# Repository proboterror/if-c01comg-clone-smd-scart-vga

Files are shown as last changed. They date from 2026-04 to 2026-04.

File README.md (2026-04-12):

IF-C01COMG Clone board SMD Full size - with SCART and DSUB-15 (VGA 15KHz) inputs.<br>
Separate H/V and combined sync supported for DSUB-15 input.

BNC connectors option removed<br>
RCA audio connectors replaced with 3.5 mm audio jack<br>
Switches changed to ALPS SPUJ190900 / SPUJ193700<br>

Project migrated to KiCad 8.

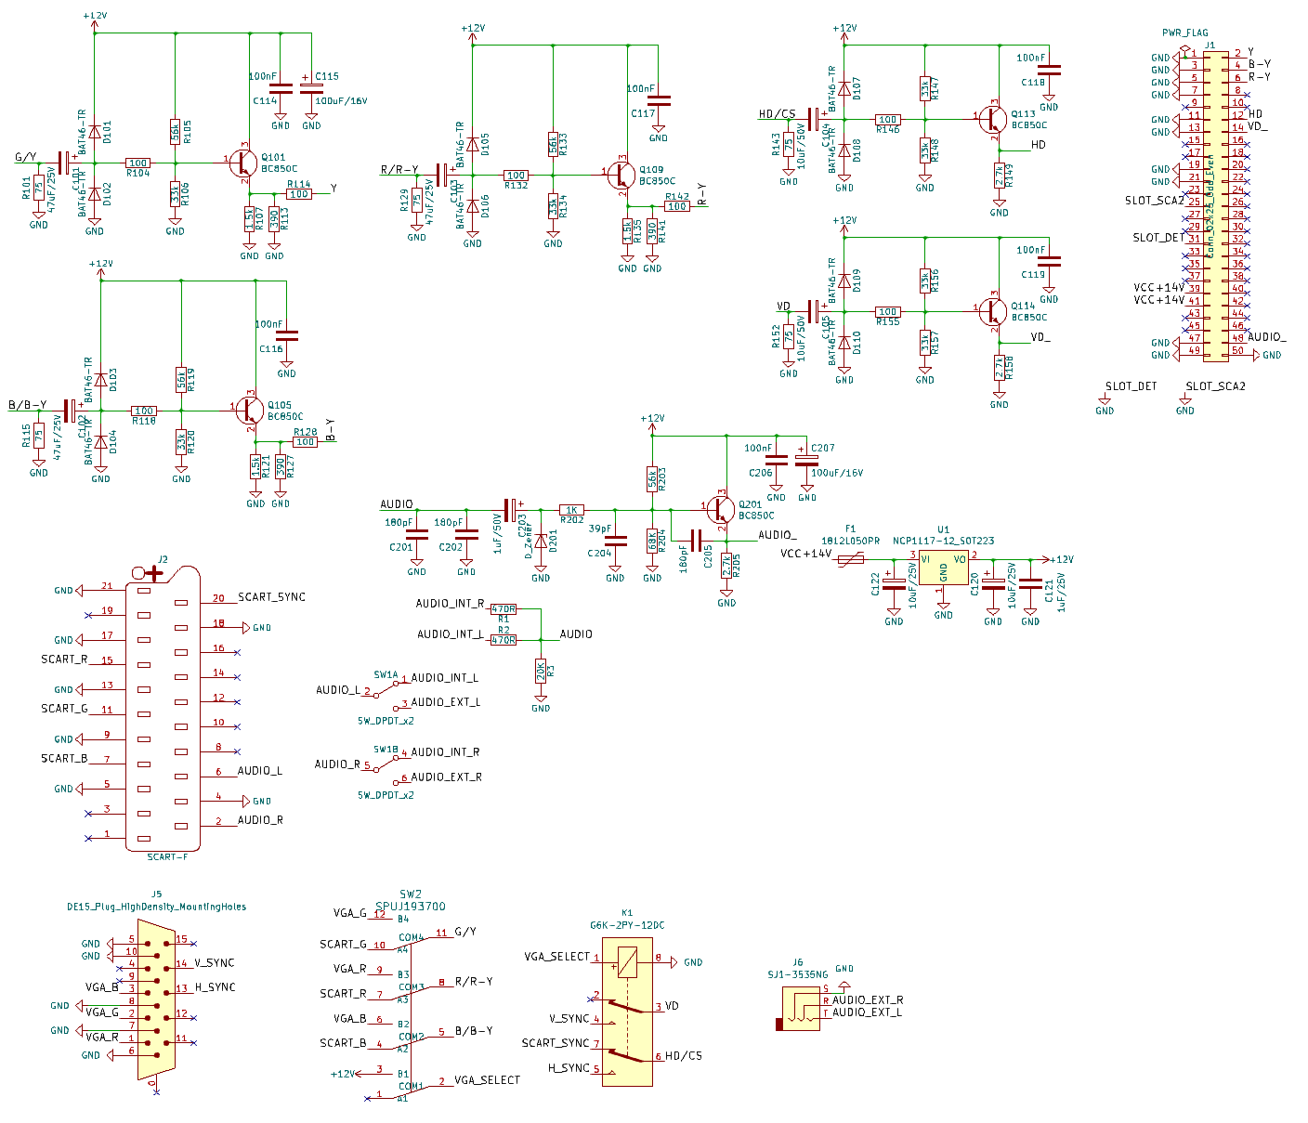
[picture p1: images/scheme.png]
scheme

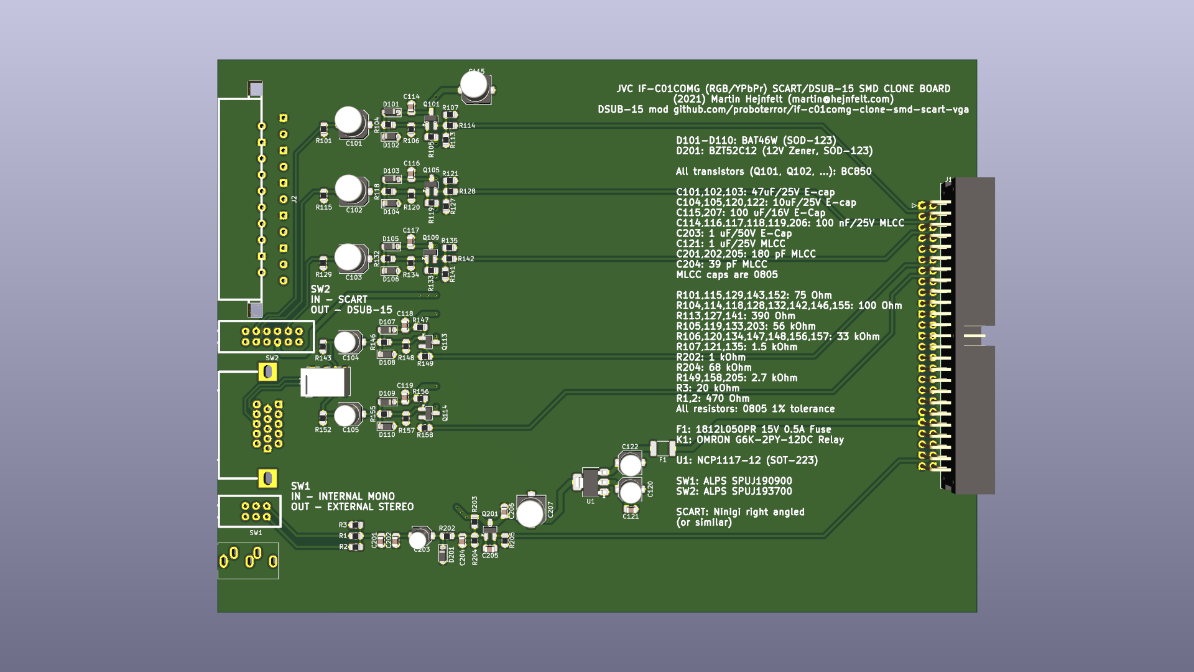
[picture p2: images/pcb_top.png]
pcb_top

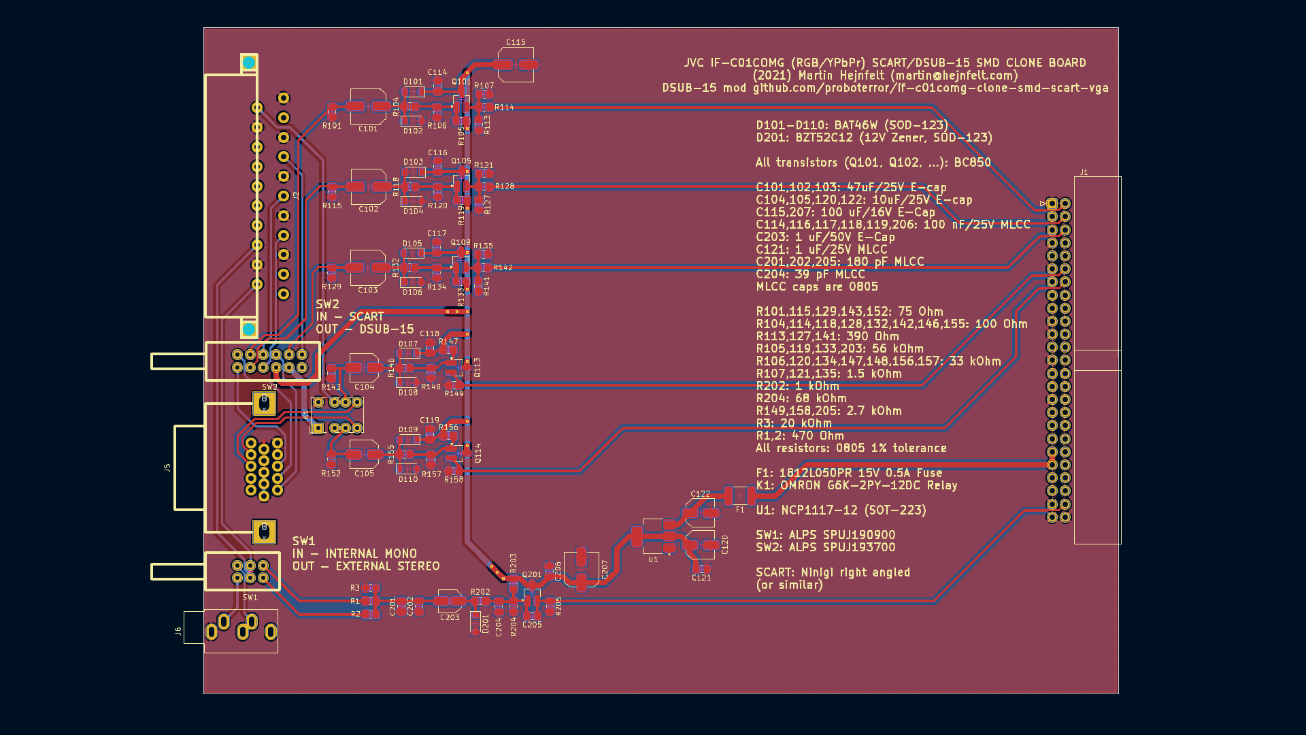
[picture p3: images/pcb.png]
pcb


## Bill of materials
|Reference|Value|Footprint|Qty|Manufacturer|SKU|
|-----|-----|-----|-----|-----|-----|
|C101,C102,C103|47uF/25V|6.3x5.4|3|PANASONIC|EEEFK1H470XP|
|||||PANASONIC|EEEFK1E470P|
|||||PANASONIC|EEEFK1E470P|
|C104,C105|10uF/50V|5x5.4|2|PANASONIC|EEEFK1H100UR|
|C114,C116,C117,C118,C119,C206|100nF|805|6|MURATA|GRM21BR71H104KA01L|
|C115,C207|100uF/16V|6.3x5.4|2|PANASONIC|EEEFK1C101P|
|C120,C122|10uF/25V|5x5.4|2|PANASONIC|EEEFK1H100UR|
|C121|1uF/25V|805|1|SAMSUNG|CL21B105KBFNNNE|
|C201,C202,C205|180pF|805|3|MURATA|GRM2165C1H181J|
|C203|1uF/50V|4x5.4|1|JB Capacitors|JCK1H010M040054|
|C204|39pF|805|1|MURATA|GRM2165C1H390J|
|D101,D102,D103,D104,D105,D106,D107,D108,D109,D110|BAT46-TR (BAT46W)|SOD-123|10|Diodes|BAT46W-7-F|
|D201|BZT52C12 (12V Zener)|SOD-123|1|Diodes|BZT52C12|
|F1|1812L050PR|Fuse_1812_4532Metric|1|Littlefuse|1812L050PR|
|J1|Conn_02x25_Odd_Even|Pin_Header_Angled_2x25_Pitch2.54mm|1|Connfly|BH-50R (DS1013-50R) (IDC-50MR)|
|J2|SCART-F||1|NINIGI|SCART-17|
|J5|DE15||1||DB15 Female Pins offset 8.5 mm Rows step 2.54 mm|
|J6|SJ1-3535NG||1|KLS Electronic|KLS1-TSJ3.5-008CBA (ST-215N-03)|
|||||KLS Electronic|KLS1-TSJ3.5-008DC (ST-215N-04)|
|||||Dragon City|ST-215N-03/ST-215N-04/ST-215N-03-SL|
|K1|G6K-2PY-12DC||1|OMRON|G6K-2PY-12DC|
|Q101,Q105,Q109,Q113,Q114,Q201|BC850C|SOT-23|6|Diotec|BC850C|
|R1,R2|470R|805|2|YAGEO|RC0805FR-07470RL|
|R3|20K|805|1|ROYAL OHM|0805S8F2002T5E|
|R101,R115,R129,R143,R152|75|805|5|ROYAL OHM|0805S8F750JT5E|
|R104,R114,R118,R128,R132,R142,R146,R155|100|805|8|YAGEO|RC0805FR-07100RL|
|R105,R119,R133,R203|56k|805|4|YAGEO|RC0805FR-0756KL|
|R106,R120,R134,R147,R148,R156,R157|33k|805|7|YAGEO|RC0805FR-0733KL|
|R107,R121,R135|1.5k|805|3|ROYAL OHM|0805S8F1501T5E|
|R113,R127,R141|390|805|3|YAGEO|RC0805FR-07390RL|
|R149,R158,R205|2.7k|805|3|YAGEO|RC0805FR-072K7L|
|R202|1K|805|1|ROYAL OHM|0805S8F1001T5E|
|R204|68K|805|1|YAGEO|RC0805FR-0768KL|
|SW1|SW_DPDT_x2||1|ALPS|SPUJ190900|
|SW2|SPUJ193700||1|ALPS|SPUJ193700|
|U1|NCP1117-12_SOT223|SOT-223|1|ONSEMI|NCP1117ST12T3G|

IF-C01COMG Clone board SMD Full size

This is a full sized version of the IF-C01COMG board for JVC pro monitors (TM-Hxx50CG) and some others...

It's basically the THT base board I made some months ago, with most components changed to SMD.

Credit goes to James Vanderloeff for the dual input idea.

Board is for now completely untested...

Finally this is a Kicad 5.1 project :D

You're welcome to clone, sell, re-design and whatever, see LICENSE.

(2021) Martin Hejnfelt (martin@hejnfelt.com)
This work is free. You can redistribute it and/or modify it under the
terms of the Do What The Fuck You Want To Public License, Version 2,
as published by Sam Hocevar. See the LICENSE file for more details.

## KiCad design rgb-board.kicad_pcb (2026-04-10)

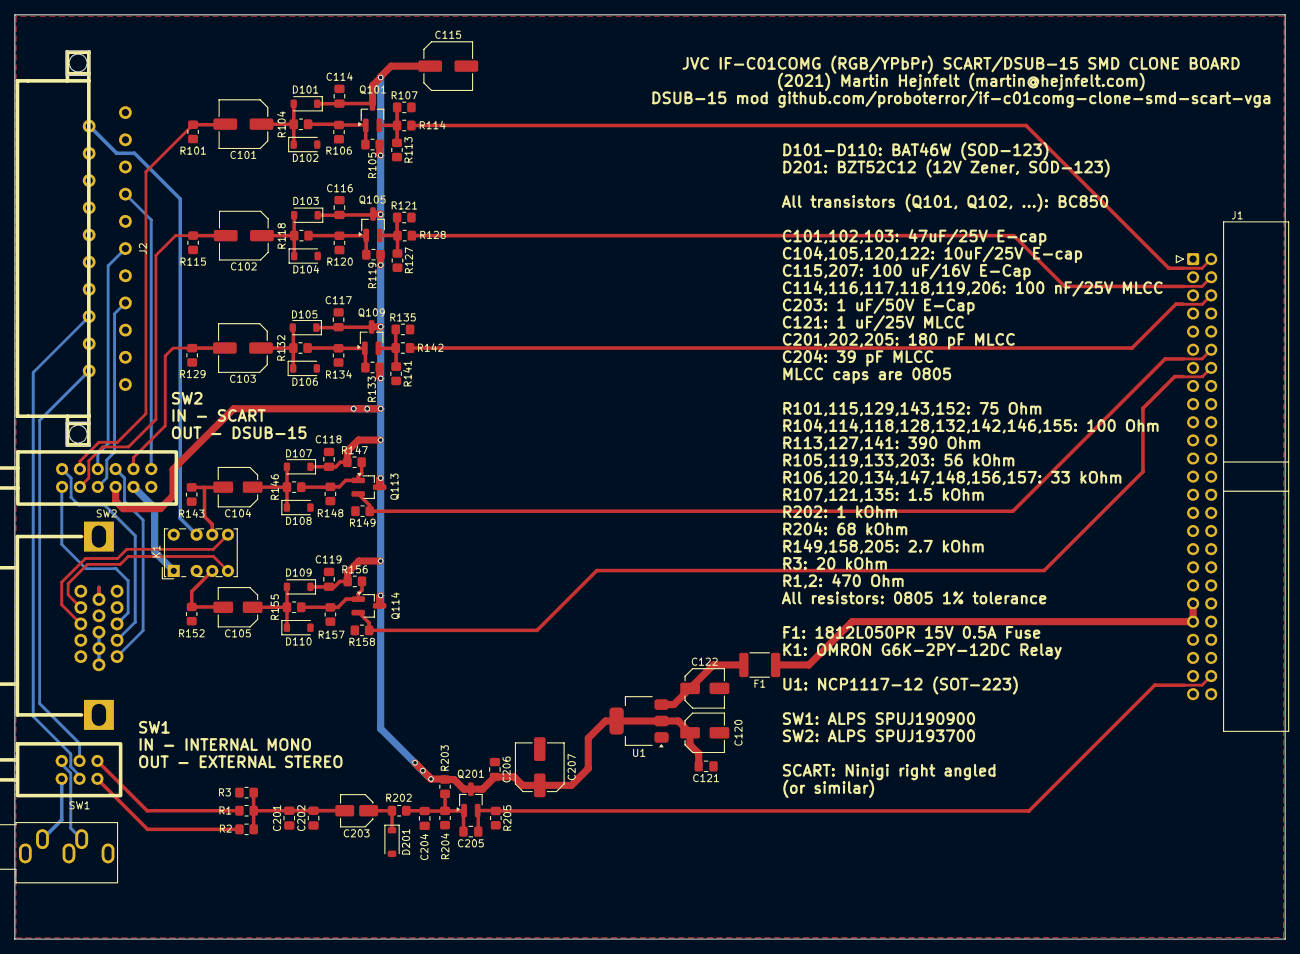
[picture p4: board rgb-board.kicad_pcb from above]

Board: 2 copper layers, 178.0 x 129.5 mm, 85 parts (0 on the bottom side), 47 nets.

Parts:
C101, C102, C103: 47uF/25V; C_Elec_6.3x5.4
C104, C105: 10uF/50V; C_Elec_5x5.4
C114, C116, C117, C118, C119, C206: 100nF; C_0805_2012Metric_Pad1.18x1.45mm_HandSolder
C115, C207: 100uF/16V; C_Elec_6.3x5.4
C120, C122: 10uF/25V; C_Elec_5x5.4
C121: 1uF/25V; C_0805_2012Metric_Pad1.18x1.45mm_HandSolder
C201, C202, C205: 180pF; C_0805_2012Metric_Pad1.18x1.45mm_HandSolder
C203: 1uF/50V; C_Elec_4x5.4
C204: 39pF; C_0805_2012Metric_Pad1.18x1.45mm_HandSolder
D101, D102, D103, D104, D105, D106, D107, D108, D109, D110: BAT46-TR; D_SOD-123
D201: D_Zener; D_SOD-123
F1: 1812L050PR; Fuse_1812_4532Metric_Pad1.30x3.40mm_HandSolder
J1: Conn_02x25_Odd_Even; IDC-Header_2x25_P2.54mm_Horizontal
J2: SCART-F; NINIGI-SCART-RA
J5: DE15_Plug_HighDensity_MountingHoles; HD15-VGA
J6: SJ1-3535NG; Jack_3.5mm_CUI_SJ1-3535NG_Horizontal
K1: G6K-2PY-12DC; Relay_DPDT_Omron_G6K-2P
Q101, Q105, Q109, Q113, Q114, Q201: BC850C; SOT-23_Handsoldering
R1, R2: 470R; R_0805_2012Metric_Pad1.20x1.40mm_HandSolder
R3: 20K; R_0805_2012Metric_Pad1.20x1.40mm_HandSolder
R101, R115, R129, R143, R152: 75; R_0805_2012Metric_Pad1.20x1.40mm_HandSolder
R104, R114, R118, R128, R132, R142, R146, R155: 100; R_0805_2012Metric_Pad1.20x1.40mm_HandSolder
R105, R119, R133, R203: 56k; R_0805_2012Metric_Pad1.20x1.40mm_HandSolder
R106, R120, R134, R147, R148, R156, R157: 33k; R_0805_2012Metric_Pad1.20x1.40mm_HandSolder
R107, R121, R135: 1.5k; R_0805_2012Metric_Pad1.20x1.40mm_HandSolder
R113, R127, R141: 390; R_0805_2012Metric_Pad1.20x1.40mm_HandSolder
R149, R158, R205: 2.7k; R_0805_2012Metric_Pad1.20x1.40mm_HandSolder
R202: 1K; R_0805_2012Metric_Pad1.20x1.40mm_HandSolder
R204: 68K; R_0805_2012Metric_Pad1.20x1.40mm_HandSolder
SW1: SW_DPDT_x2; SPUJ190900
SW2: SPUJ193700
U1: NCP1117-12_SOT223; SOT-223-3_TabPin2

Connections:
+12V: C114.2, C115.1, C116.2, C117.2, C118.2, C119.2, C120.1, C121.2, C206.2, C207.1, D101.1 (K), D103.1 (K), D105.1 (K), D107.1 (K), D109.1 (K), Q101.3 (C), Q105.3 (C), Q109.3 (C), Q113.3 (C), Q114.3 (C), Q201.3 (C), R105.1, R119.1, R133.1, R147.1, R156.1, R203.1, SW2.3 (B1), U1.2 (VO)
/AUDIO: C201.2, C202.2, C203.2, R1.1, R2.2, R3.1
/AUDIO_: C205.1, J1.48, Q201.2 (E), R205.1
/AUDIO_EXT_L: J6.T, SW1.3 (C)
/AUDIO_EXT_R: J6.R, SW1.6 (C)
/AUDIO_INT_L: R2.1, SW1.1 (A)
/AUDIO_INT_R: R1.2, SW1.4 (A)
/AUDIO_L: J2.6, SW1.2 (B)
/AUDIO_R: J2.2, SW1.5 (B)
/B-Y: J1.4, R128.2
/B/B-Y: C102.2, R115.1, SW2.5 (COM2)
/G/Y: C101.2, R101.1, SW2.11 (COM4)
/HD: J1.12, Q113.2 (E), R149.1
/HD/CS: C104.2, K1.6, R143.1
/H_SYNC: J5.13, K1.5
/R-Y: J1.6, R142.2
/R/R-Y: C103.2, R129.1, SW2.8 (COM3)
/SCART_B: J2.7, SW2.4 (A2)
/SCART_G: J2.11, SW2.10 (A4)
/SCART_R: J2.15, SW2.7 (A3)
/SCART_SYNC: J2.20, K1.7
/VCC+14V: F1.1, J1.39, J1.41
/VD: C105.2, K1.3, R152.1
/VD_: J1.14, Q114.2 (E), R158.1
/VGA_B: J5.3, SW2.6 (B2)
/VGA_G: J5.2, SW2.12 (B4)
/VGA_R: J5.1, SW2.9 (B3)
/VGA_SELECT: K1.1, SW2.2 (COM1)
/V_SYNC: J5.14, K1.4
/Y: J1.2, R114.2
GND: C114.1, C115.2, C116.1, C117.1, C118.1, C119.1, C120.2, C121.1, C122.2, C201.1, C202.1, C204.1, C206.1, C207.2, D102.2 (A), D104.2 (A), D106.2 (A), D108.2 (A), D110.2 (A), D201.2 (A), J1.1, J1.3, J1.5, J1.7, J1.11, J1.13, J1.19, J1.21, J1.25, J1.31, J1.47, J1.49, J1.50, J2.4, J2.5, J2.9, J2.13, J2.17, J2.18, J2.21, J5.5, J5.6, J5.7, J5.8, J5.10, J6.S, K1.8, R3.2, R101.2, R106.2, R107.2, R113.2, R115.2, R120.2, R121.2, R127.2, R129.2, R134.2, R135.2, R141.2, R143.2, R148.2, R149.2, R152.2, R157.2, R158.2, R204.2, R205.2, U1.1 (GND)
unnamed: C101.1, D101.2 (A), D102.1 (K), R104.2
unnamed: C102.1, D103.2 (A), D104.1 (K), R118.2
unnamed: C103.1, D105.2 (A), D106.1 (K), R132.2
unnamed: C104.1, D107.2 (A), D108.1 (K), R146.2
unnamed: C105.1, D109.2 (A), D110.1 (K), R155.2
unnamed: C203.1, D201.1 (K), R202.2
unnamed: Q101.1 (B), R104.1, R105.2, R106.1
unnamed: Q101.2 (E), R107.1, R113.1, R114.1
unnamed: Q105.1 (B), R118.1, R119.2, R120.1
unnamed: Q105.2 (E), R121.1, R127.1, R128.1
unnamed: Q109.1 (B), R132.1, R133.2, R134.1
unnamed: Q109.2 (E), R135.1, R141.1, R142.1
unnamed: Q113.1 (B), R146.1, R147.2, R148.1
unnamed: Q114.1 (B), R155.1, R156.2, R157.1
unnamed: C204.2, C205.2, Q201.1 (B), R202.1, R203.2, R204.1
unnamed: C122.1, F1.2, U1.3 (VI)

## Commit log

2026-02-18 Update project to KiCad 8.
    [rgb-board.kicad_pcb, rgb-board.kicad_sch]
2026-02-18 Remove BNC connectors.
    [rgb-board.kicad_pcb, rgb-board.kicad_sch]
2026-02-18 Add DSUB-15 VGA Connector. Custom footprint from https://github.com/skumlos/bkm-129x-scart-vga Note pins rows spacing 2.54 mm.
    [rgb-board.kicad_pcb, rgb-board.kicad_sch]
2026-02-18 Add ALPS SPUJ Series SPUJ193700 4PDT switch. Custom Push Button 4PDT symbol from https://github.com/skumlos/bkm-129x-scart-vga Custom E-Switch PBH4UEE 4PDT switch footprint from https://github.com/sk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
    [rgb-board.kicad_pcb, rgb-board.kicad_sch]
2026-02-18 Add OMRON G6K-2PY-12DC Miniature Relay Dual Pole DPDT.
    [rgb-board.kicad_pcb, rgb-board.kicad_sch]
2026-02-18 Add CUI Devices / SAME SKY Devices SJ1-353XNG Series Audio Jack 3.5 mm Female.
    [rgb-board.kicad_pcb, rgb-board.kicad_sch]
2026-02-18 Remove audio RCA connectors.
    [rgb-board.kicad_pcb, rgb-board.kicad_sch]
2026-02-18 Edit PCB edge.
    [rgb-board.kicad_pcb]
2026-02-18 SCART / VGA switching schematic.
    [rgb-board.kicad_sch]
2026-02-18 Add ALPS SPUJ Series push switches footprints library. Replace LC2259 and PBH4UEE push switches with ALPS SPUJ190900 and SPUJ193700. Remove LC2259 and PBH4UEE footprints.
    [rgb-board.kicad_pcb, rgb-board.kicad_sch]
2026-02-18 Edit SCART connector footprint silkscreen.
    [rgb-board.kicad_pcb]
2026-02-18 Route PCB.
    +14V power line polyfuse added.
    [rgb-board.kicad_pcb, rgb-board.kicad_sch]
2026-02-18 Update PCB silkscreen description.
    [rgb-board.kicad_pcb]
2026-02-18 Update footprints from KiCad global library.
    [rgb-board.kicad_pcb]
2026-02-18 Add GND fill exclude zone for 2x25 IDC connector. Edit SW1 silkscreen description.
    [rgb-board.kicad_pcb]
2026-02-19 Correct R203, R205 resistors marking for BoM.
    [rgb-board.kicad_sch]
2026-02-19 Oval mounting holes for DSUB-15/VGA connector.
    [rgb-board.kicad_pcb]
2026-02-24 Square mounting pads for DSUB-15.
    [rgb-board.kicad_pcb]
2026-04-10 Fixed Relay_DPDT_Omron_G6K-2P footprint pins spacing according to datasheet. Footprint copied from KiCad 8.0.0 global library to project.
    Fixed BOM duplicated values.
    [rgb-board.kicad_pcb, rgb-board.kicad_sch]
